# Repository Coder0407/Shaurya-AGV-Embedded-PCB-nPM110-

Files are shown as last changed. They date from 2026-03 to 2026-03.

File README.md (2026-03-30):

# Shaurya-AGV-Embedded-PCB-nPM110-

This project involves the design and layout of a high-efficiency Power Management Module based on the Nordic nPM1100 PMIC. The board is engineered to provide a robust 3V logic rail at a nominal 200ma charging rate.
The PCB follows a 2-Layer approach where Copper Pour(Ground) has been done on both planes with a primary focus on maintaining a solid, contiguous Ground Plane on the bottom layer. By minimizing signal routing on the bottom a low-impedance return path for the high-frequency switching currents is ensured 
The Designs prioritises Power integrety , a effort has been made into ensuring minimum SW- trace and keeping the decoupling capacitors as close as possible with multiple ground vias attached to them
Various LED for power CHG and ERR are placed , MCU is exposed to multiple pins including CHG ERR Mode SHPACT and a battery charge monitering system has been introduced.
A switch has also been connected to SHPLD to turn on the IC manually.
Values of various Pins like VSET and resistance like R_ICHG are tune to ensure a 200ma nominal charging current and a max 4.2VBAT with the data from the datasheet.
In the battery monitering system the MCU is given controll through Q1 and Q2 on when to measure the battery voltage, to reduce power loss .

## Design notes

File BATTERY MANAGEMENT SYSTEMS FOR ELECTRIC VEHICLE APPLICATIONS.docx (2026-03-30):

BATTERY MANAGEMENT SYSTEMS FOR ELECTRIC VEHICLE APPLICATIONS

Theory And Concepts

This paper introduces many theoretical concepts which I will explain in this section-

1. SOC – State Of Charge, It refers to the amount of charge left in a battery , normally it takes the rated capacity of a new battery cell as 100%.
2. SOH- State Of Health: It basically reflects the overall health of a battery how much capacity it has with respect to the original capacity.
3. Colomb Counting: Is a method to calculate SOC by basically integrating the current over time to get the charge that has left the batter, it can be reasonably accurate when temperature and discharge rate variations are also taken into account.
4. Voltage Delay Method- This method is generally used when the battery is outside the car, a transient load is applied across the battery and its voltage response is calculated to get the SOC of the battery
5. Impedance spectroscopy: It is a method that can calculate both SOC and SOH where an applied signal which is small amplitude, ac waveform is given to the battery and its voltage and current responses are observed, however this method is expensive and temperature sensitive.
6. Peukert’s Equation- it is a equation which says that , the discharge current of a battery decreases with increasing the discharge time. And gives the following relation

I^n * T = constant

Here n is a battery constant and T is time to discharge at current .

7. Fuzzy Logic Methodology: Instead of using binary this logic allows values between 0 and 1 allowing more possibilities and can be used in uncertain conditions.

PROBLEM ADDRESSED

The problems the BMS addresses is very simple , Batteries are volatile in nature their total capacity changes over the time , we are at times unable to find out the charge left in a battery, this may cause overcharging of the battery, This can cause major problems like Cell imbalance (in case of multiple cell usage), cell overcharging (normal charging or in cases like regenerative braking) or overdischarging . Both of these events are a major cause of battery failure. There is also an issue of overheating where a cell may even burn causing safety hazards.

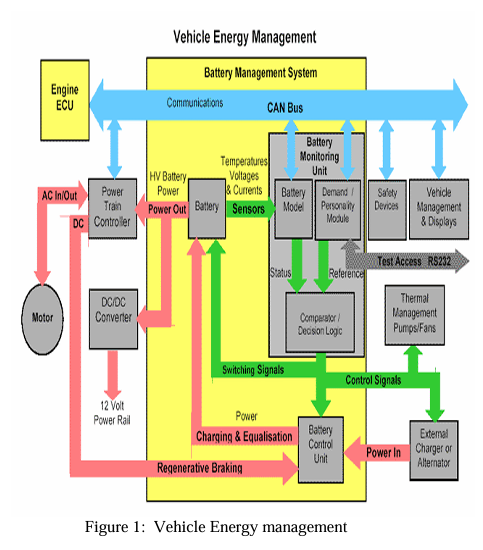
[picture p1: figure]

METHOD PROPOSED

The proposed solution is implementation of a BMS system consisting of three units BCU (Battery Control Unit), BMU(Battery Monitoring Unit), CAN BUS .

In the proposed solution BMS uses impedence response at various specific frequencies to find out many different things including SOC using SOC algorithms based on peukerts’s equation .

it also measures the temperature of battery . It also goes about and stores a history of charge and discharge cycles to estimate SOH.

For this two types of memory are proposed one is the ROM(Read only memory ) which stores the information about current, temperature , EMF if the SOC algorithm is based on it, and all of there relations with SOC are stored here.

Second is RAM in which history of charge and discharge cycles are stored.

Finally the BMS uses the fuzzy logic methodology and looks whether the SOC or the temperature are going beyond the acceptable range and if yes it disconnects the DC link and turns on the alarm

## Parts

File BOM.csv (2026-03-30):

 | Qty | Value | DNP | Exclude from BOM | Exclude from Board | Footprint | Datasheet | Manufacturer | Manufacturer part number | Supplier | Supplier Part number
Battery1 | 1 | 4R2V |  |  |  | Connector_JST:JST_PH_B2B-PH-SM4-TB_1x02-1MP_P2.00mm_Vertical |  | JST | B2B-PH-SM4-TB(LF)(SN) | LSCS | C160352
C1 | 1 | 1u_10V_X5R |  |  |  | Capacitor_SMD:C_0603_1608Metric_Pad1.08x0.95mm_HandSolder | ~ | YAGEO | CC0603KRX5R6BB105 | Mouser Electronics` | 603-CC603KRX5R6BB105
C2 | 1 | 2R2uF_10V_X5R |  |  |  | Capacitor_SMD:C_0603_1608Metric_Pad1.08x0.95mm_HandSolder | ~ | Samsung Electro-Mechanics | CL10A225KP8NNWC | Mouser Electronics` | 187-CL10A225KP8NNWC | `
C3 | 1 | 10uF_6.3V_X5R |  |  |  | Capacitor_SMD:C_0603_1608Metric_Pad1.08x0.95mm_HandSolder | ~ | Samsung Electro-Mechanics | CL10A106KP8NQSC | Mouser Electronics` | 187-CL10A106KP8NQSC
C4,C5 | 2 | 10uF_10V_X5R |  |  |  | Capacitor_SMD:C_0603_1608Metric_Pad1.08x0.95mm_HandSolder | ~ | Samsung Electro-Mechanics | CL10A106KP8NQSC | Mouser Electronics` | 187-CL10A106KP8NQSC
D1,D2,D3 | 3 | LED |  |  |  | LED_SMD:LED_0603_1608Metric_Pad1.05x0.95mm_HandSolder | ~ | Wurth Elektronik | 150060RS83000 | Mouser Electronics` | 710-150060RS83000
J1 | 1 | Conn_01x02_Pin |  |  |  | Connector_PinHeader_2.54mm:PinHeader_1x02_P2.54mm_Vertical_SMD_Pin1Left | ~ | Samtec Inc. | TSM-102-01-L-SV | Digikey | SAM8979-ND
L1 | 1 | 2R2uH |  |  |  | Inductor_SMD:L_0603_1608Metric_Pad1.05x0.95mm_HandSolder | ~ | Murata Electronics | LQW18FT2R2K0HL | Mouser Electronics` | 81-LQW18FT2R2K0HL
MCU_HEADER1 | 1 | Conn_01x08_Pin |  |  |  | Connector_PinHeader_2.54mm:PinHeader_1x08_P2.54mm_Vertical_SMD_Pin1Left | ~ | Mill-Max | 419-10-208-30-055000 | Mouser Electronics` | 575-4191020830055000
Q1,Q2 | 2 | BSS138 |  |  |  | Package_TO_SOT_SMD:SOT-23 | https://www.onsemi.com/pub/Collateral/BSS138-D.PDF | onsemi | BSS138 | Mouser Electronics` | 512-BSS138
R2,R5 | 1 | 1M0 |  |  |  | Resistor_SMD:R_0603_1608Metric_Pad0.98x0.95mm_HandSolder | ~ | Vishay | CRCW06037K15FKEC | Mouser Electronics` | 71-CRCW06037K15FKEC
R3 | 1 | 1M5 |  |  |  | Resistor_SMD:R_0603_1608Metric_Pad0.98x0.95mm_HandSolder | ~ | Vishay / Draloric | RCS06031M50FKEA | Mouser Electronics` | 71-RCS06031M50FKEA
R4 | 1 | 220K |  |  |  | Resistor_SMD:R_0603_1608Metric_Pad0.98x0.95mm_HandSolder | ~ | Vishay / Draloric | RCS0603220KFKEA | Mouser Electronics` | 71-RCS0603220KFKEA
R6 | 1 | 100K |  |  |  | Resistor_SMD:R_0603_1608Metric_Pad0.98x0.95mm_HandSolder | ~ | Vishay Dale | CRCW0603100KFKEA | DigiKey | 541-100KHDKR-ND
R_ICHG1 | 1 | 1K5 |  |  |  | Resistor_SMD:R_0603_1608Metric_Pad0.98x0.95mm_HandSolder | ~ | Susumu | RG1608P-152-B-T5 | DigiKey | RG16P1.5KBDKR-ND
R_ICHG2 | 1 | 1K |  |  |  | Resistor_SMD:R_0603_1608Metric_Pad0.98x0.95mm_HandSolder | ~ | Stackpole Electronics Inc | RMCF0603FT1K00 | DigiKey | RMCF0603FT1K00DKR-ND
SW2 | 1 | SW_Push |  |  |  | Button_Switch_SMD:SW_Push_1P1T_NO_CK_KMR2 | ~ | C&K | KMR232NG ULC LFS | Mouser Electronics` | 611-KMR232NGULCLFS
TH1 | 1 | Thermistor_NTC |  |  |  | Resistor_SMD:R_0603_1608Metric_Pad0.98x0.95mm_HandSolder | ~ | TDK | NTCSP164KF104FT1H | Mouser Electronics` | 810-NTCSP164KF104FT1
U1 | 1 | VALUE |  |  |  | Package_DFN_QFN:HVQFN-24-1EP_4x4mm_P0.5mm_EP2.6x2.6mm_ThermalVias |  | Nordic Semiconductor ASA | 4823-NPM1100-QDAA-RDKR-ND | DigiKey | 4823-NPM1100-QDAA-RDKR-ND

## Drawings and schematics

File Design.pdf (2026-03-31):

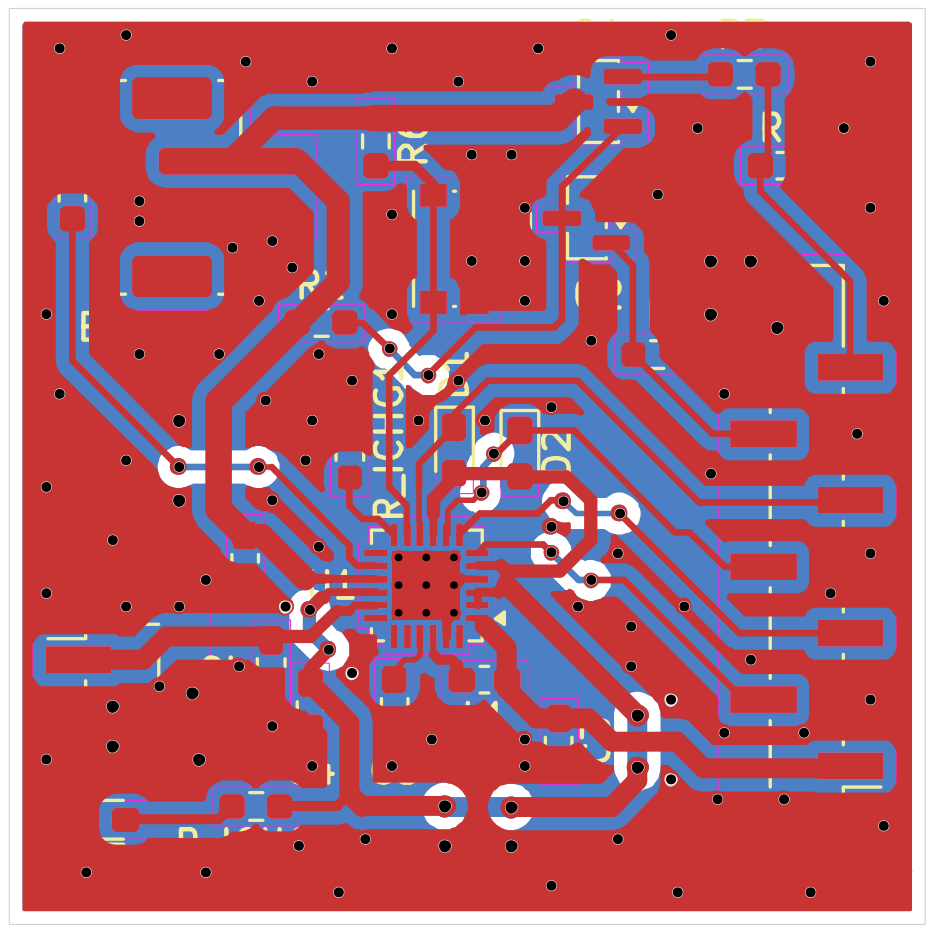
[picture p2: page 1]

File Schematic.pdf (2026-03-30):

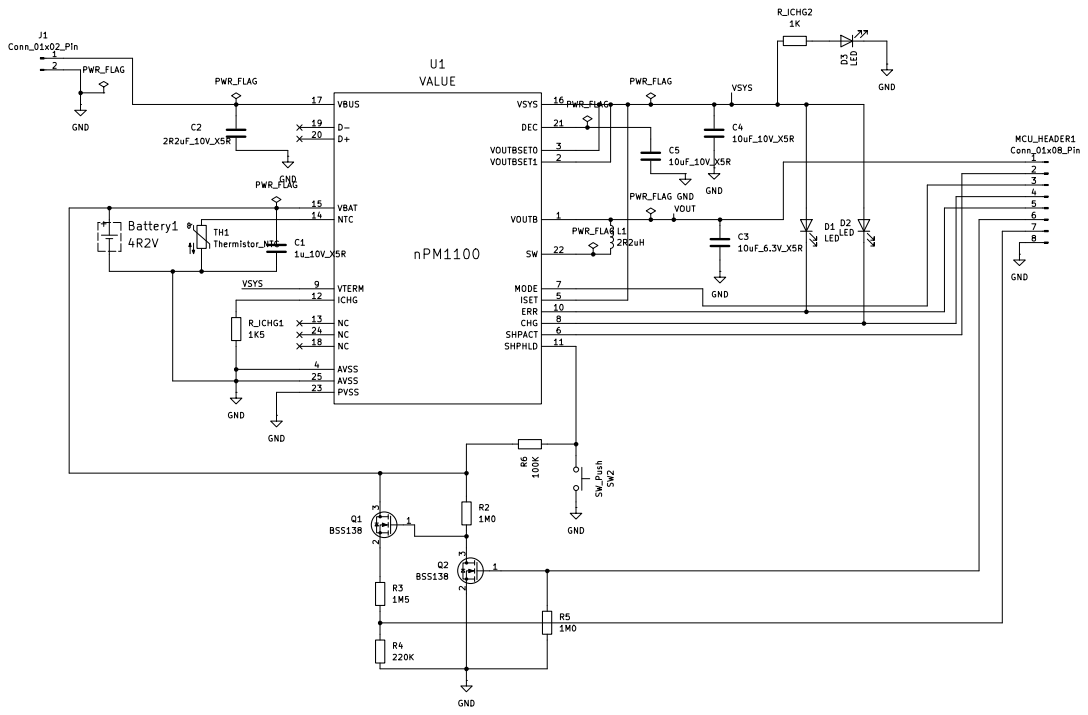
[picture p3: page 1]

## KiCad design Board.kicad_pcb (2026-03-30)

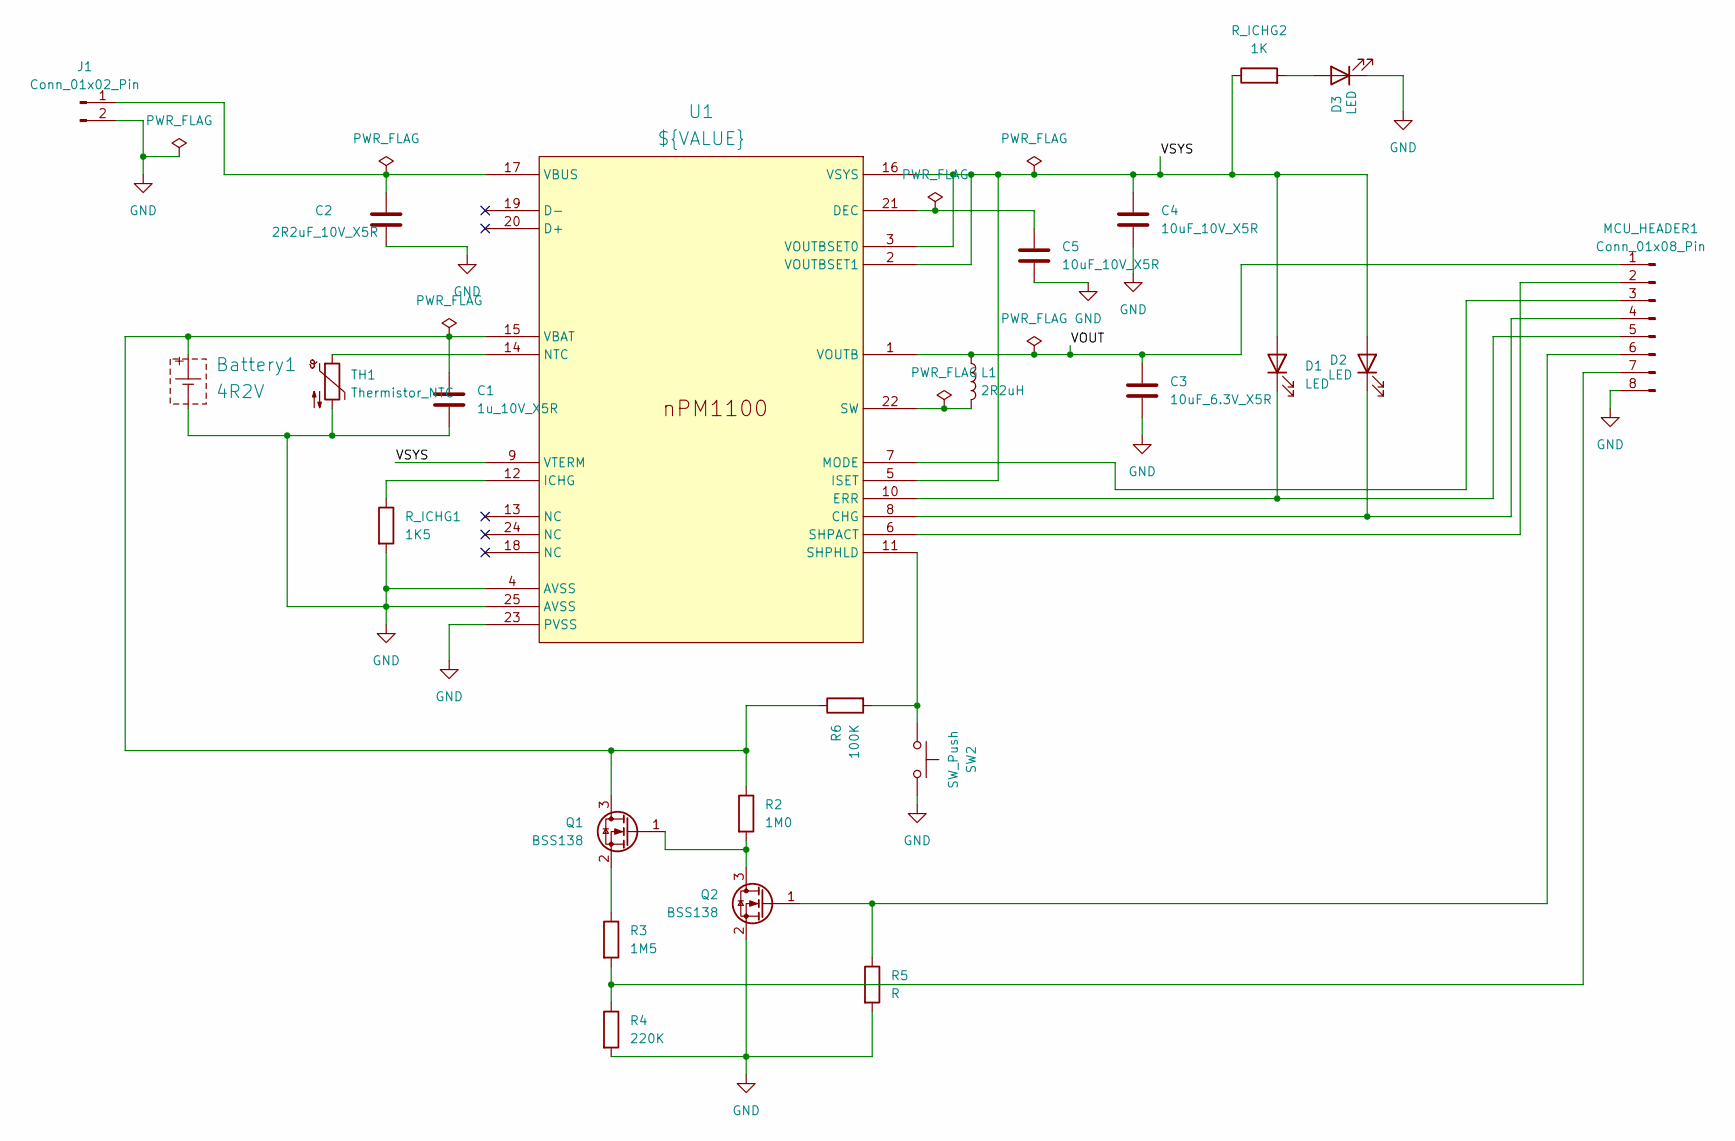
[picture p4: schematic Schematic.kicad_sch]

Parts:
Battery1: 4R2V; JST_PH_B2B-PH-SM4-TB_1x02-1MP_P2.00mm_Vertical
C1: 1u_10V_X5R; C_0603_1608Metric_Pad1.08x0.95mm_HandSolder
C2: 2R2uF_10V_X5R; C_0603_1608Metric_Pad1.08x0.95mm_HandSolder
C3: 10uF_6.3V_X5R; C_0603_1608Metric_Pad1.08x0.95mm_HandSolder
C4, C5: 10uF_10V_X5R; C_0603_1608Metric_Pad1.08x0.95mm_HandSolder
D1, D2, D3: LED; LED_0603_1608Metric_Pad1.05x0.95mm_HandSolder
J1: Conn_01x02_Pin; PinHeader_1x02_P2.54mm_Vertical_SMD_Pin1Left
L1: 2R2uH; L_0603_1608Metric_Pad1.05x0.95mm_HandSolder
MCU_HEADER1: Conn_01x08_Pin; PinHeader_1x08_P2.54mm_Vertical_SMD_Pin1Left
Q1, Q2: BSS138; SOT-23
R2: 1M0; R_0603_1608Metric_Pad0.98x0.95mm_HandSolder
R3: 1M5; R_0603_1608Metric_Pad0.98x0.95mm_HandSolder
R4: 220K; R_0603_1608Metric_Pad0.98x0.95mm_HandSolder
R5: R; R_0603_1608Metric_Pad0.98x0.95mm_HandSolder
R6: 100K; R_0603_1608Metric_Pad0.98x0.95mm_HandSolder
R_ICHG1: 1K5; R_0603_1608Metric_Pad0.98x0.95mm_HandSolder
R_ICHG2: 1K; R_0603_1608Metric_Pad0.98x0.95mm_HandSolder
SW2: SW_Push; SW_Push_1P1T_NO_CK_KMR2
TH1: Thermistor_NTC; R_0603_1608Metric_Pad0.98x0.95mm_HandSolder
U1: ${VALUE}; HVQFN-24-1EP_4x4mm_P0.5mm_EP2.6x2.6mm_ThermalVias

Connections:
/VOUT: C3.1, L1.1, MCU_HEADER1.1, U1.1 (VOUTB)
/VSYS: C4.1, D1.2 (A), D2.2 (A), R_ICHG2.1, U1.2 (VOUTBSET1), U1.3 (VOUTBSET0), U1.5 (ISET), U1.9 (VTERM), U1.16 (VSYS)
GND: Battery1.1 (GND), C1.2, C2.2, C3.2, C4.2, C5.2, D3.1 (K), J1.2, MCU_HEADER1.8, Q2.2 (S), R4.2, R5.2, R_ICHG1.2, SW2.1, TH1.2, U1.4 (AVSS), U1.23 (PVSS), U1.25 (AVSS)
unnamed: Battery1.2 (V+), C1.1, Q1.3 (D), R2.1, R6.1, U1.15 (VBAT)
unnamed: D1.1 (K), MCU_HEADER1.5, U1.10 (ERR)
unnamed: D2.1 (K), MCU_HEADER1.4, U1.8 (CHG)
unnamed: D3.2 (A), R_ICHG2.2
unnamed: C2.1, J1.1, U1.17 (VBUS)
unnamed: MCU_HEADER1.2, U1.6 (SHPACT)
unnamed: MCU_HEADER1.3, U1.7 (MODE)
unnamed: MCU_HEADER1.6, Q2.1 (G), R5.1
unnamed: MCU_HEADER1.7, R3.2, R4.1
unnamed: Q1.1 (G), Q2.3 (D), R2.2
unnamed: Q1.2 (S), R3.1
unnamed: C5.1, U1.21 (DEC)
unnamed: R_ICHG1.1, U1.12 (ICHG)
unnamed: TH1.1, U1.14 (NTC)
unnamed: R6.2, SW2.2, U1.11 (SHPHLD)
unnamed: L1.2, U1.22 (SW)

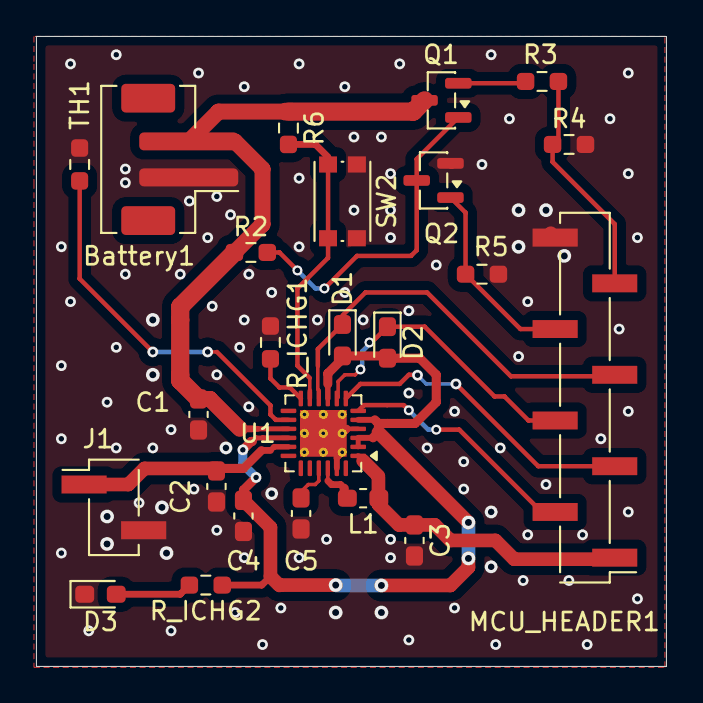
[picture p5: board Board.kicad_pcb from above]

Board: 2 copper layers, 35.0 x 35.0 mm, 24 parts (0 on the bottom side), 19 nets.
